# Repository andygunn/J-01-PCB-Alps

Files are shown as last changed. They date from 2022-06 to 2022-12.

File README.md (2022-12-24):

# J-01 Alps PCB

This is an Alps compatible PCB for the [J-01 keyboard](https://geekhack.org/index.php?topic=107597). Many thanks to Flex, the designer of the original PCB for their help with dimensions and layout compatibility. Additional thanks to Anjheos for the help with adding J-01 rev2 compatibility.

While it lacks support for MX switches, it has Alps switch support and the following additional features:
- Full bottom row support per the options in Via (see the following [Keyboard Layout](http://www.keyboard-layout-editor.com/#/gists/1aa1c3e0d55bc183d22bc74a1a26bc83) for more information).
- Normal, stepped, and 3800-style Capslock footprints.
- ISO Enter support - including for 1.25U vertical and horizontal rotation (Matias, DCS?), and 1.5U vertical orientation (Dell AT102).
- Some hand-solderable SMT component support, though the ATmega32U4-MU MCU is not hand-solderable.
- This PCB maintains PCB-mount MX stabilizer support, as most modern Alps keysets relased now have MX-style stabilizers. Using a plate with MX-style stabilizer cutouts will be requried to use those.

Some notable changes from the original J-01 rev1 PCB:
- Dual ground planes, instead of the GND / 5V plane on the original. It appears that the 5V ground plane on the original facilitated easier routing of the LED 5V signal, as well as power to the MCU. Since this Alps version of the PCB does not utilize in-switch LED footprints, this was changed.
- The spacing of the 6U spacebar stabilizer is different. I am not sure if the original PCB has these incorrect, or if I am using a different 6U spacebar stabilizer footprint, but that is a discrepancy.

## I provide this PCB without liability and without any guarantees regarding functionality, as expressed in the licenses under which this PCB is licensed.

Front render:
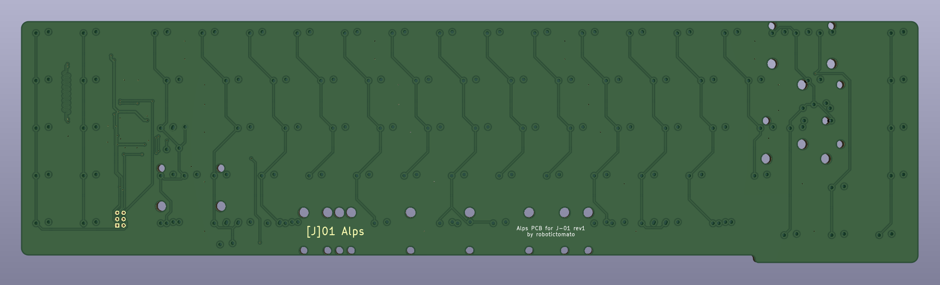
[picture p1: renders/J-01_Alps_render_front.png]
Render of front of J-01 Alps PCB


Back render:
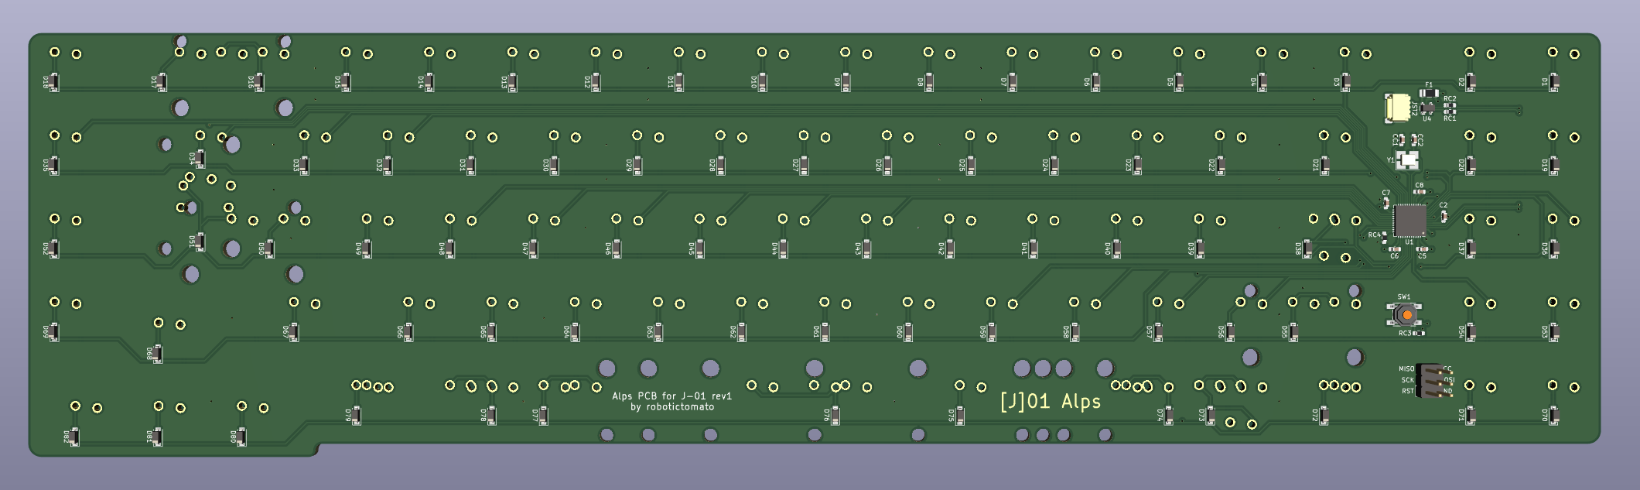
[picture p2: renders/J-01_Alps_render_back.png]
Render of back of J-01 Alps PCB


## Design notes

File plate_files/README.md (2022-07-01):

# J-01 Alps Plate Files

These are some Alps-compatible plate files for the [J-01 keyboard](https://geekhack.org/index.php?topic=107597). These are derived from the original plate files found on the [Prototypist website](https://prototypist.net/pages/resources).

There are three files provided. These are:
* A .dxf of an Alps-stabilizer file. This utilizes an AT101 bottom row, but older Alps sets were all a bit different, so you may encounter issues with the placement of the stabilizer clips and the vertical pole guide. There are cutouts for a flipped spacebar orientation, but this is untested. You may need to adjust for your specific keyset.
* A .dxf of an MX-stabilizer file. This is close to the production plate for the J-01 rev1, but with Alps switch cutouts. This is intended for DCS-style keycaps, with MX-stabilizer compatibility on all stabilized keys. Other keysets may not work, you may need to adjust for your specific keyset. NOTE: This plate has not been fully tested, you may run into issues.
* A set of Gerber files based on the MX-stabilizer file. The same notes and disclaimers apply here. NOTE: This plate has not been prototyped or tested in any way, you may run into issues.

It is recommended to cut these files in material 1.2mm thick - any thicker may prevent the Alps switches from clipping in properly.

## I provide these plate files without liability and without any guarantees regarding functionality, as expressed in the licenses under which these plate files are licensed.

Alps-stabilizer plate file outline:
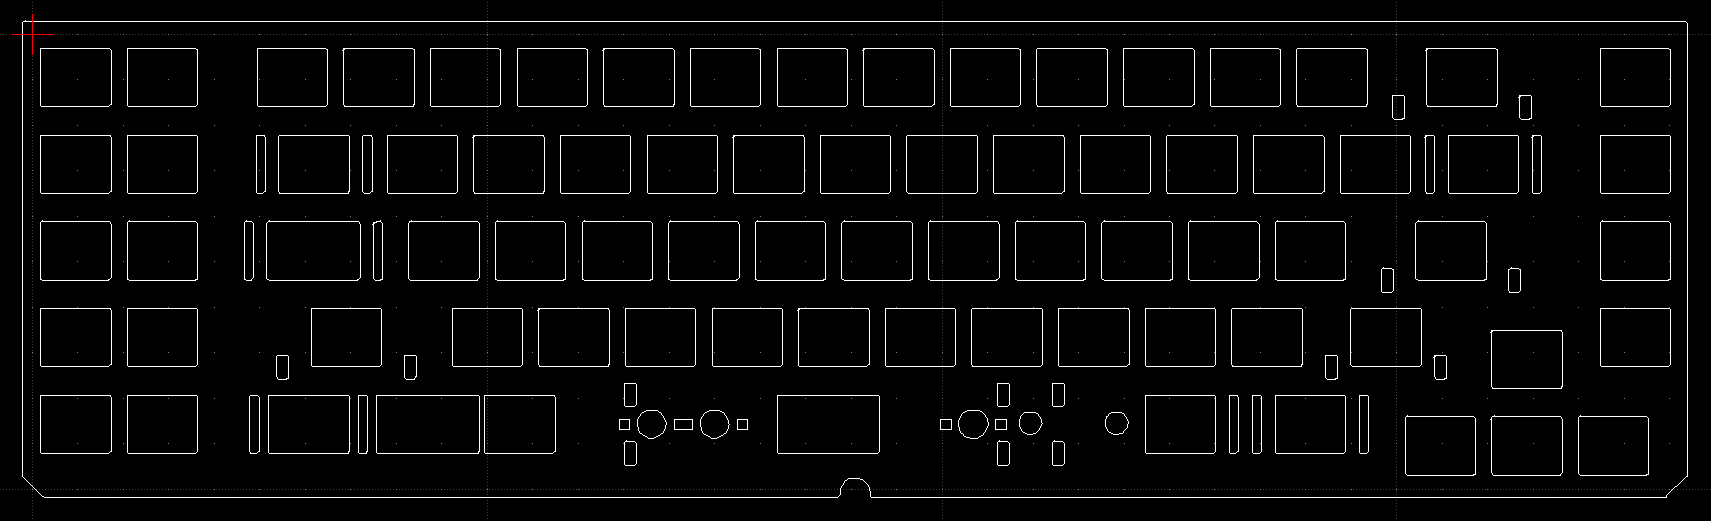
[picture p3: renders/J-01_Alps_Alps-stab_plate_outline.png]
Screenshot of Alps-stabilizer plate file


MX stabilizer plate file outline:
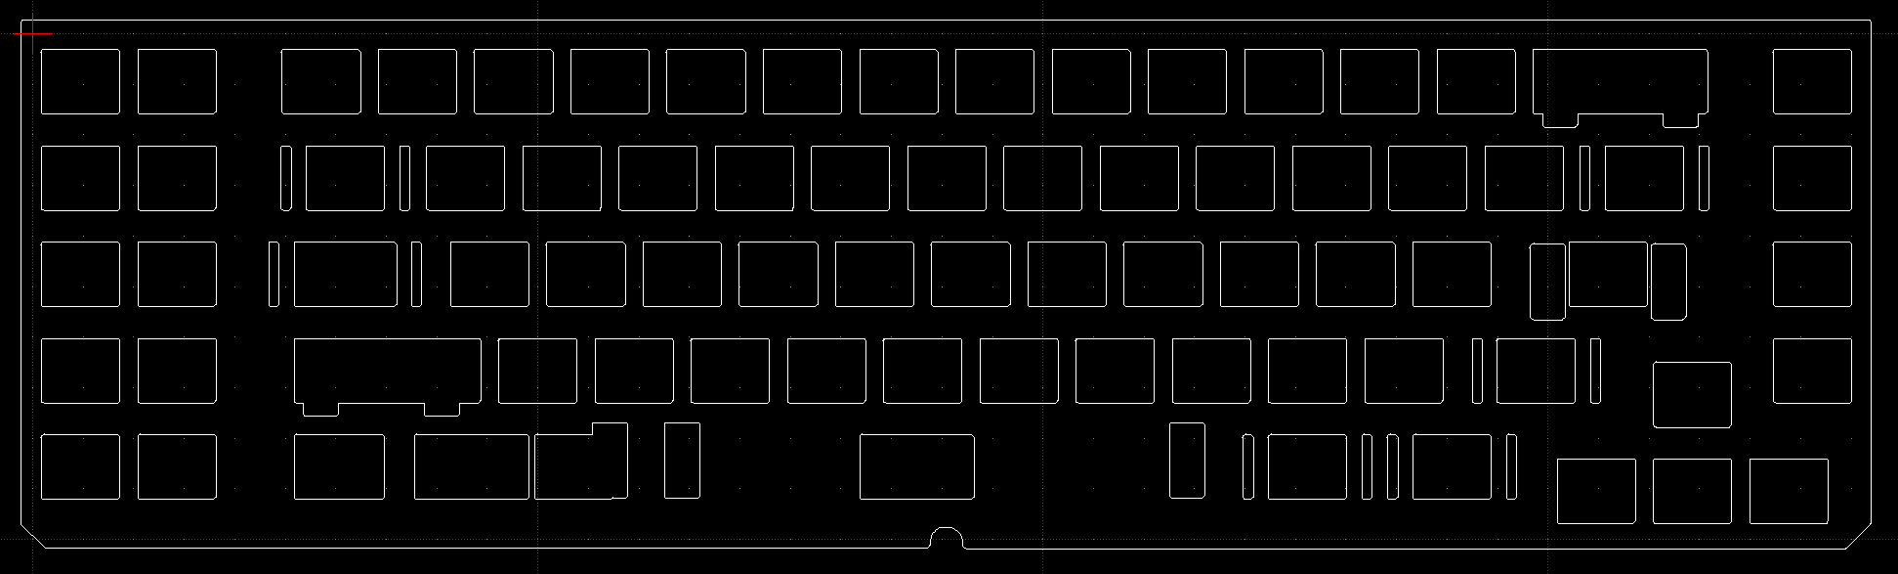
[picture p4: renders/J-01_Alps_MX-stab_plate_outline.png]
Screenshot of MX-stabilizer plate file


FR4 plate file render:
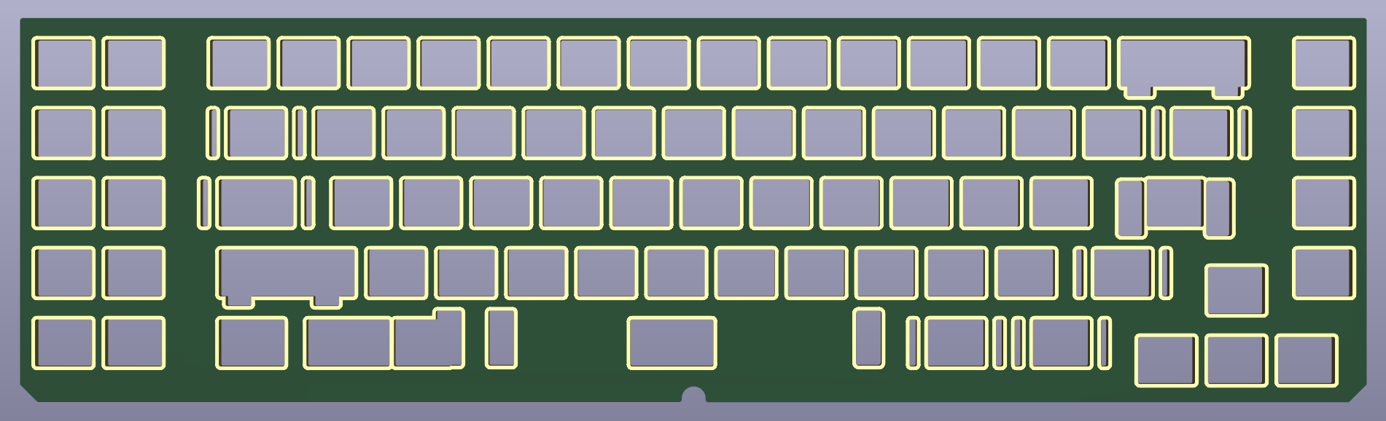
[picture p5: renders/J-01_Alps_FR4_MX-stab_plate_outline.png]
Render of J-01 Alps FR4 plate file


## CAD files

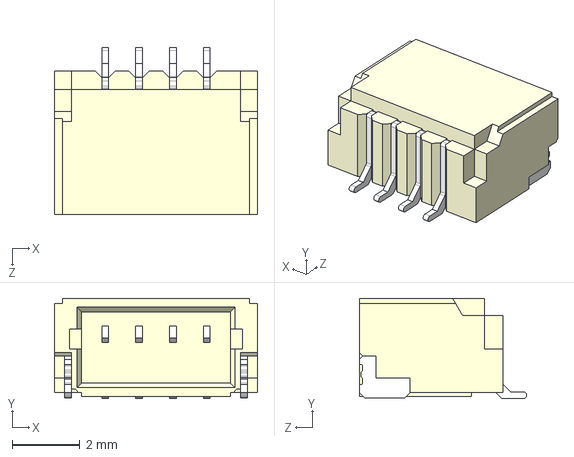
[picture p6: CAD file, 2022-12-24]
JST-3d-model/SM04B-SRSS-TB(LF)(SN)--3DModel-STEP-56544.STEP
6.00 x 2.96 x 4.95 mm

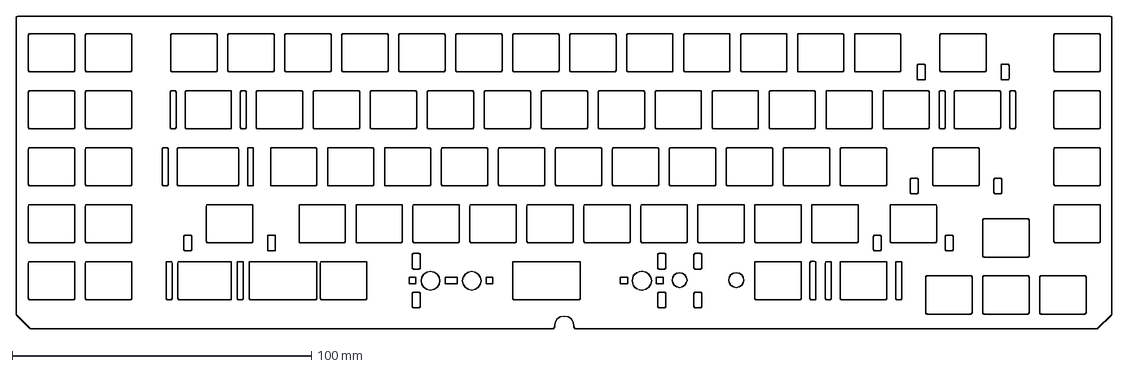
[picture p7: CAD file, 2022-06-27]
plate_files/J-01Rev-1_Alps_-_Alps-stabs.dxf
366.3 x 104.6 mm

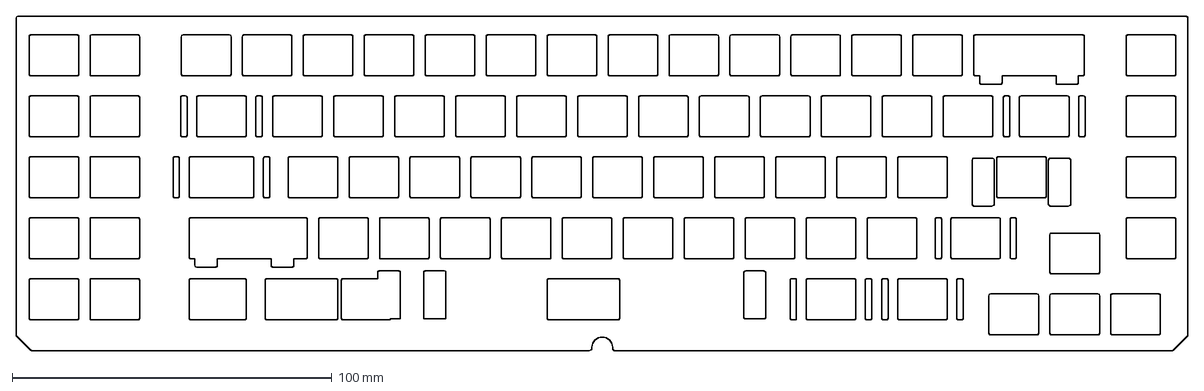
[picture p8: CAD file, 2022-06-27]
plate_files/J-01Rev-1_Alps_-_MX stabs.dxf
366.3 x 104.6 mm

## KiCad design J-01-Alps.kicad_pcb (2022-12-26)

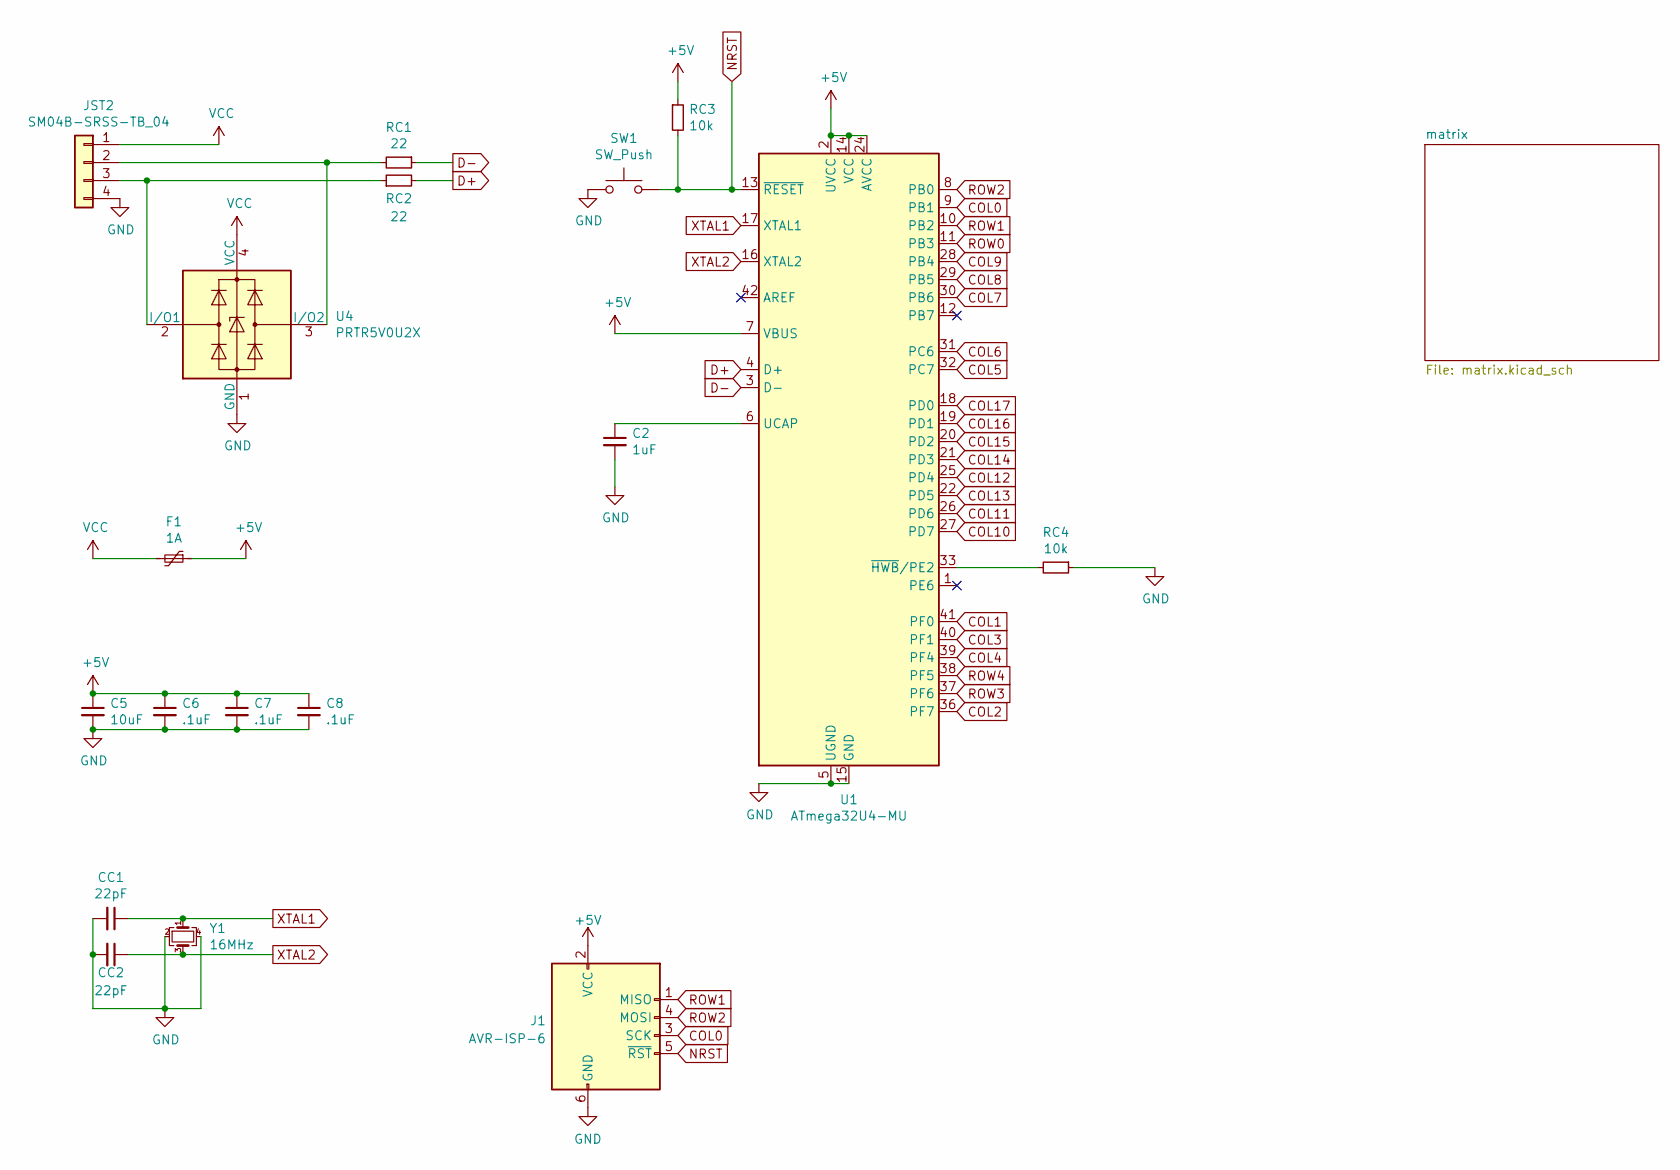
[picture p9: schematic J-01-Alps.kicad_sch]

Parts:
C2: 1uF; C_0603_1608Metric_Pad1.08x0.95mm_HandSolder; LCSC C15849
C5: 10uF; C_0603_1608Metric_Pad1.08x0.95mm_HandSolder; LCSC C19702
C6, C7, C8: .1uF; C_0603_1608Metric_Pad1.08x0.95mm_HandSolder; LCSC C14663
CC1, CC2: 22pF; C_0603_1608Metric_Pad1.08x0.95mm_HandSolder; LCSC C1653
F1: 1A; Fuse_1206_3216Metric_Pad1.42x1.75mm_HandSolder; LCSC C315893
J1: AVR-ISP-6; PinHeader_2x03_P2.54mm_Vertical
JST2: SM04B-SRSS-TB_04; JST_SH_SM04B-SRSS-TB_1x04-1MP_P1.00mm_Horizontal; LCSC C160404
RC1, RC2: 22; R_0603_1608Metric_Pad0.98x0.95mm_HandSolder; LCSC C23345
RC3, RC4: 10k; R_0603_1608Metric_Pad0.98x0.95mm_HandSolder; LCSC C25804
SW1: SW_Push; SKQGADE010
U1: ATmega32U4-MU; QFN-44-1EP_7x7mm_P0.5mm_EP5.15x5.15mm
U4: PRTR5V0U2X; SOT143B; LCSC C12333
Y1: 16MHz; Crystal_SMD_3225-4Pin_3.2x2.5mm_HandSoldering; LCSC C255906

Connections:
+5V: C5.1, C6.1, C7.1, C8.1, F1.1, J1.2 (VCC), RC3.1, U1.2 (UVCC), U1.7 (VBUS), U1.14 (VCC), U1.24 (AVCC), U1.34 (VCC), U1.44 (AVCC)
COL0: J1.3 (SCK), U1.9 (PB1); also elsewhere on the board
COL1: U1.41 (PF0); also elsewhere on the board
COL2: U1.36 (PF7); also elsewhere on the board
COL3: U1.40 (PF1); also elsewhere on the board
COL4: U1.39 (PF4); also elsewhere on the board
COL5: U1.32 (PC7); also elsewhere on the board
COL6: U1.31 (PC6); also elsewhere on the board
COL7: U1.30 (PB6); also elsewhere on the board
COL8: U1.29 (PB5); also elsewhere on the board
COL9: U1.28 (PB4); also elsewhere on the board
COL10: U1.27 (PD7); also elsewhere on the board
COL11: U1.26 (PD6); also elsewhere on the board
COL12: U1.25 (PD4); also elsewhere on the board
COL13: U1.22 (PD5); also elsewhere on the board
COL14: U1.21 (PD3); also elsewhere on the board
COL15: U1.20 (PD2); also elsewhere on the board
COL16: U1.19 (PD1); also elsewhere on the board
COL17: U1.18 (PD0); also elsewhere on the board
D+: RC2.2, U1.4 (D+)
D-: RC1.1, U1.3 (D-)
GND: C2.2, C5.2, C6.2, C7.2, C8.2, CC1.2, CC2.2, J1.6 (GND), JST2.4, RC4.1, SW1.1, U1.5 (UGND), U1.15 (GND), U1.23 (GND), U1.35 (GND), U1.43 (GND), U4.1 (GND), Y1.2, Y1.4
NRST: J1.5 (~RST), RC3.2, SW1.2, U1.13 (~RESET)
unnamed: C2.1, U1.6 (UCAP)
unnamed: JST2.2, RC1.2, U4.3 (I/O2)
unnamed: JST2.3, RC2.1, U4.2 (I/O1)
unnamed: RC4.2, U1.33 (~HWB/PE2)
ROW0: U1.11 (PB3); also elsewhere on the board
ROW1: J1.1 (MISO), U1.10 (PB2); also elsewhere on the board
ROW2: J1.4 (MOSI), U1.8 (PB0); also elsewhere on the board
ROW3: U1.37 (PF6); also elsewhere on the board
ROW4: U1.38 (PF5); also elsewhere on the board
VCC: F1.2, JST2.1, U4.4 (VCC)
XTAL1: CC1.1, U1.17 (XTAL1), Y1.1
XTAL2: CC2.1, U1.16 (XTAL2), Y1.3

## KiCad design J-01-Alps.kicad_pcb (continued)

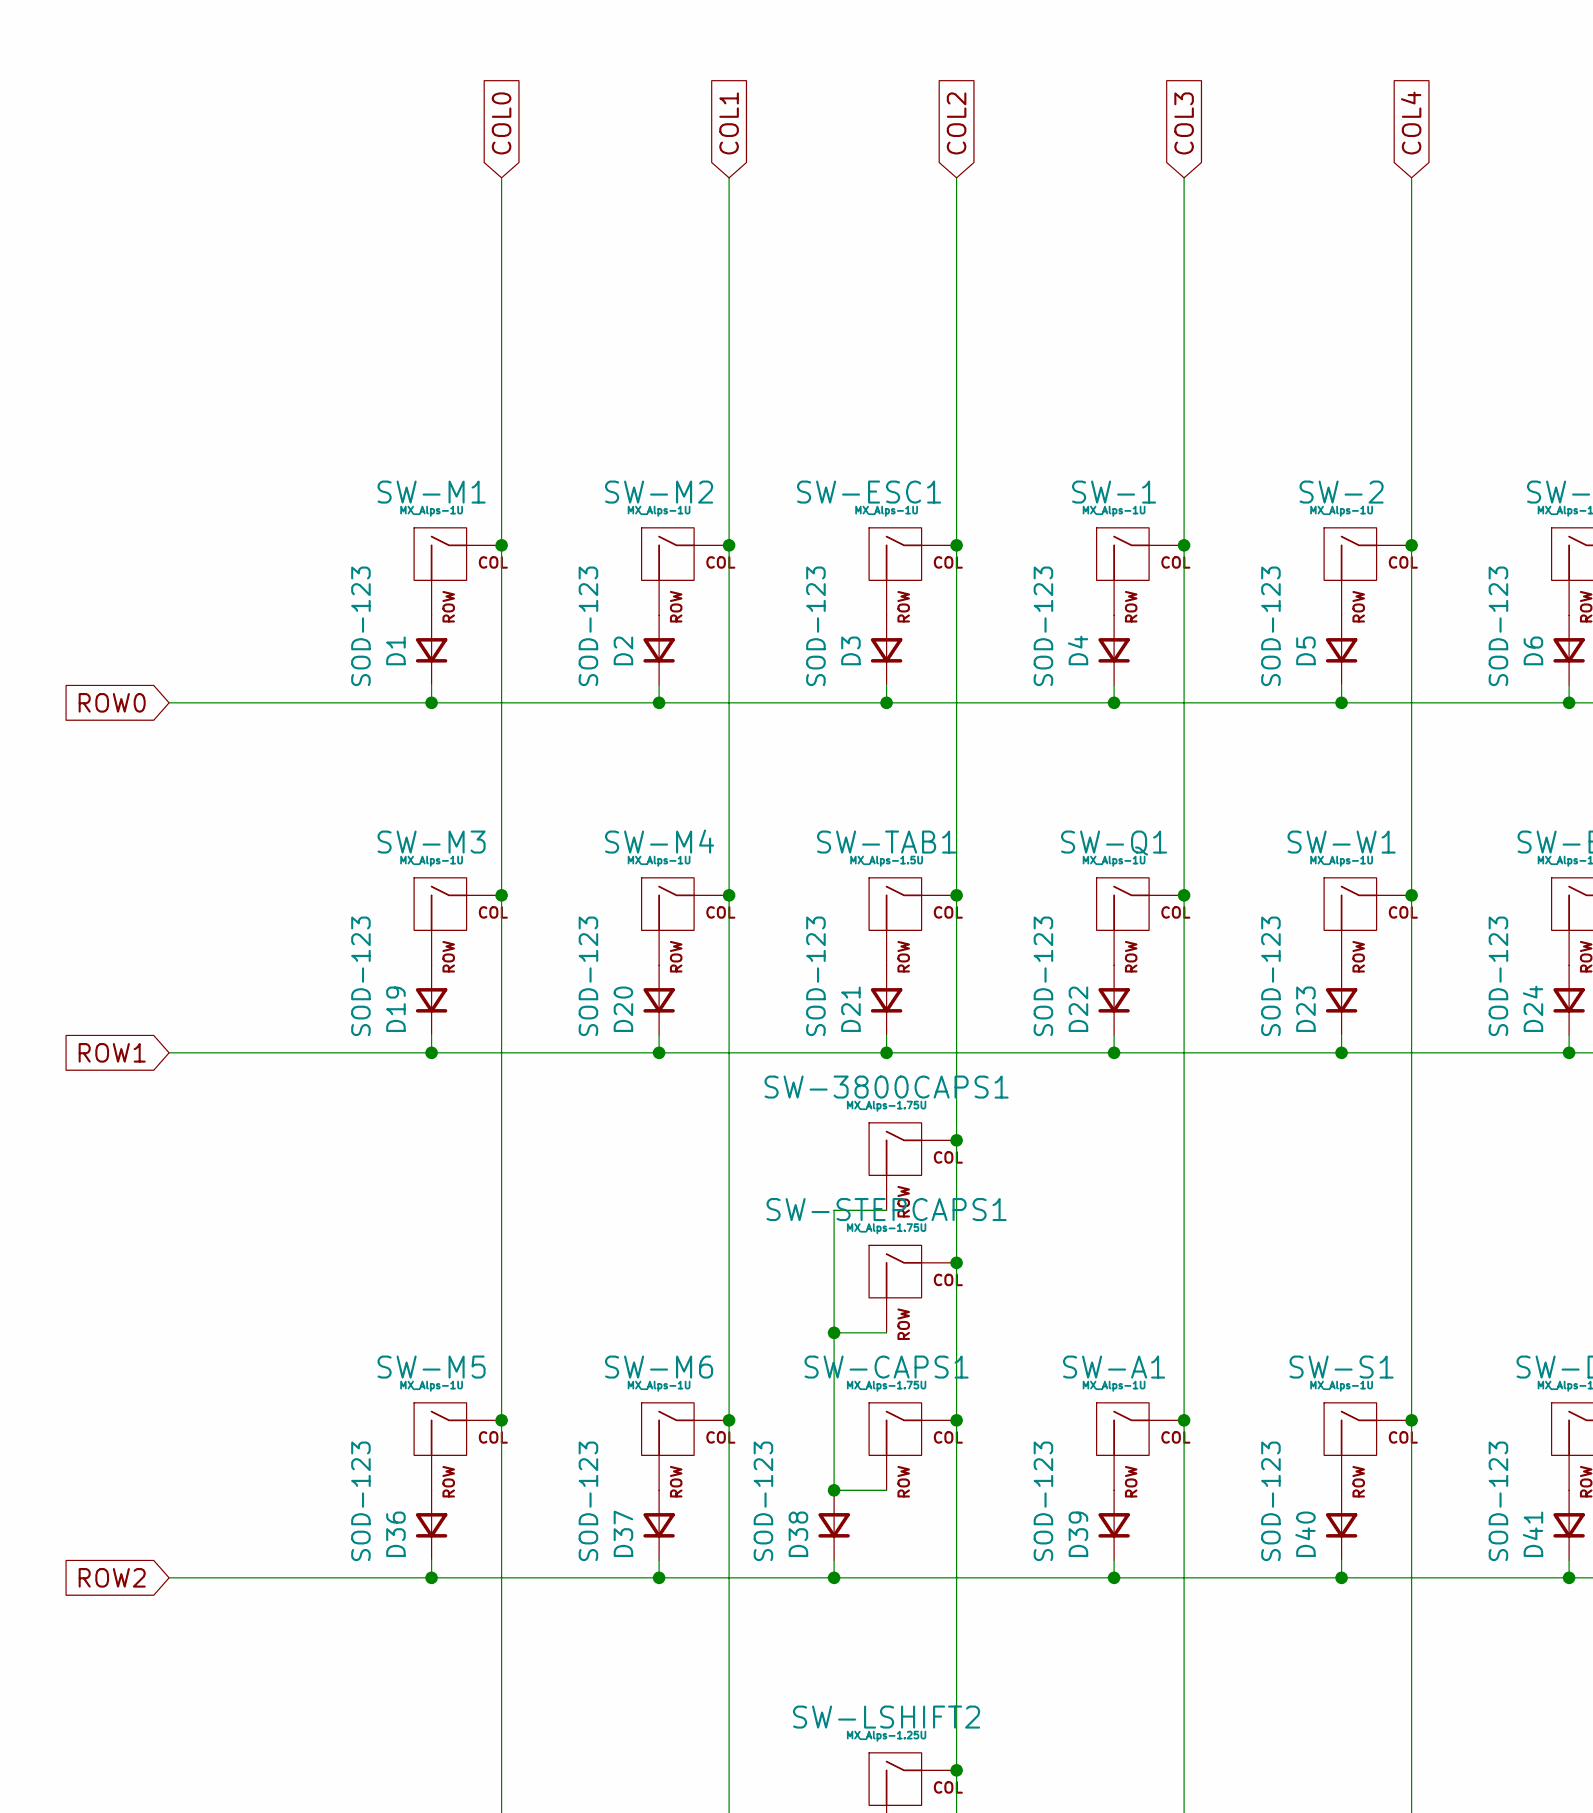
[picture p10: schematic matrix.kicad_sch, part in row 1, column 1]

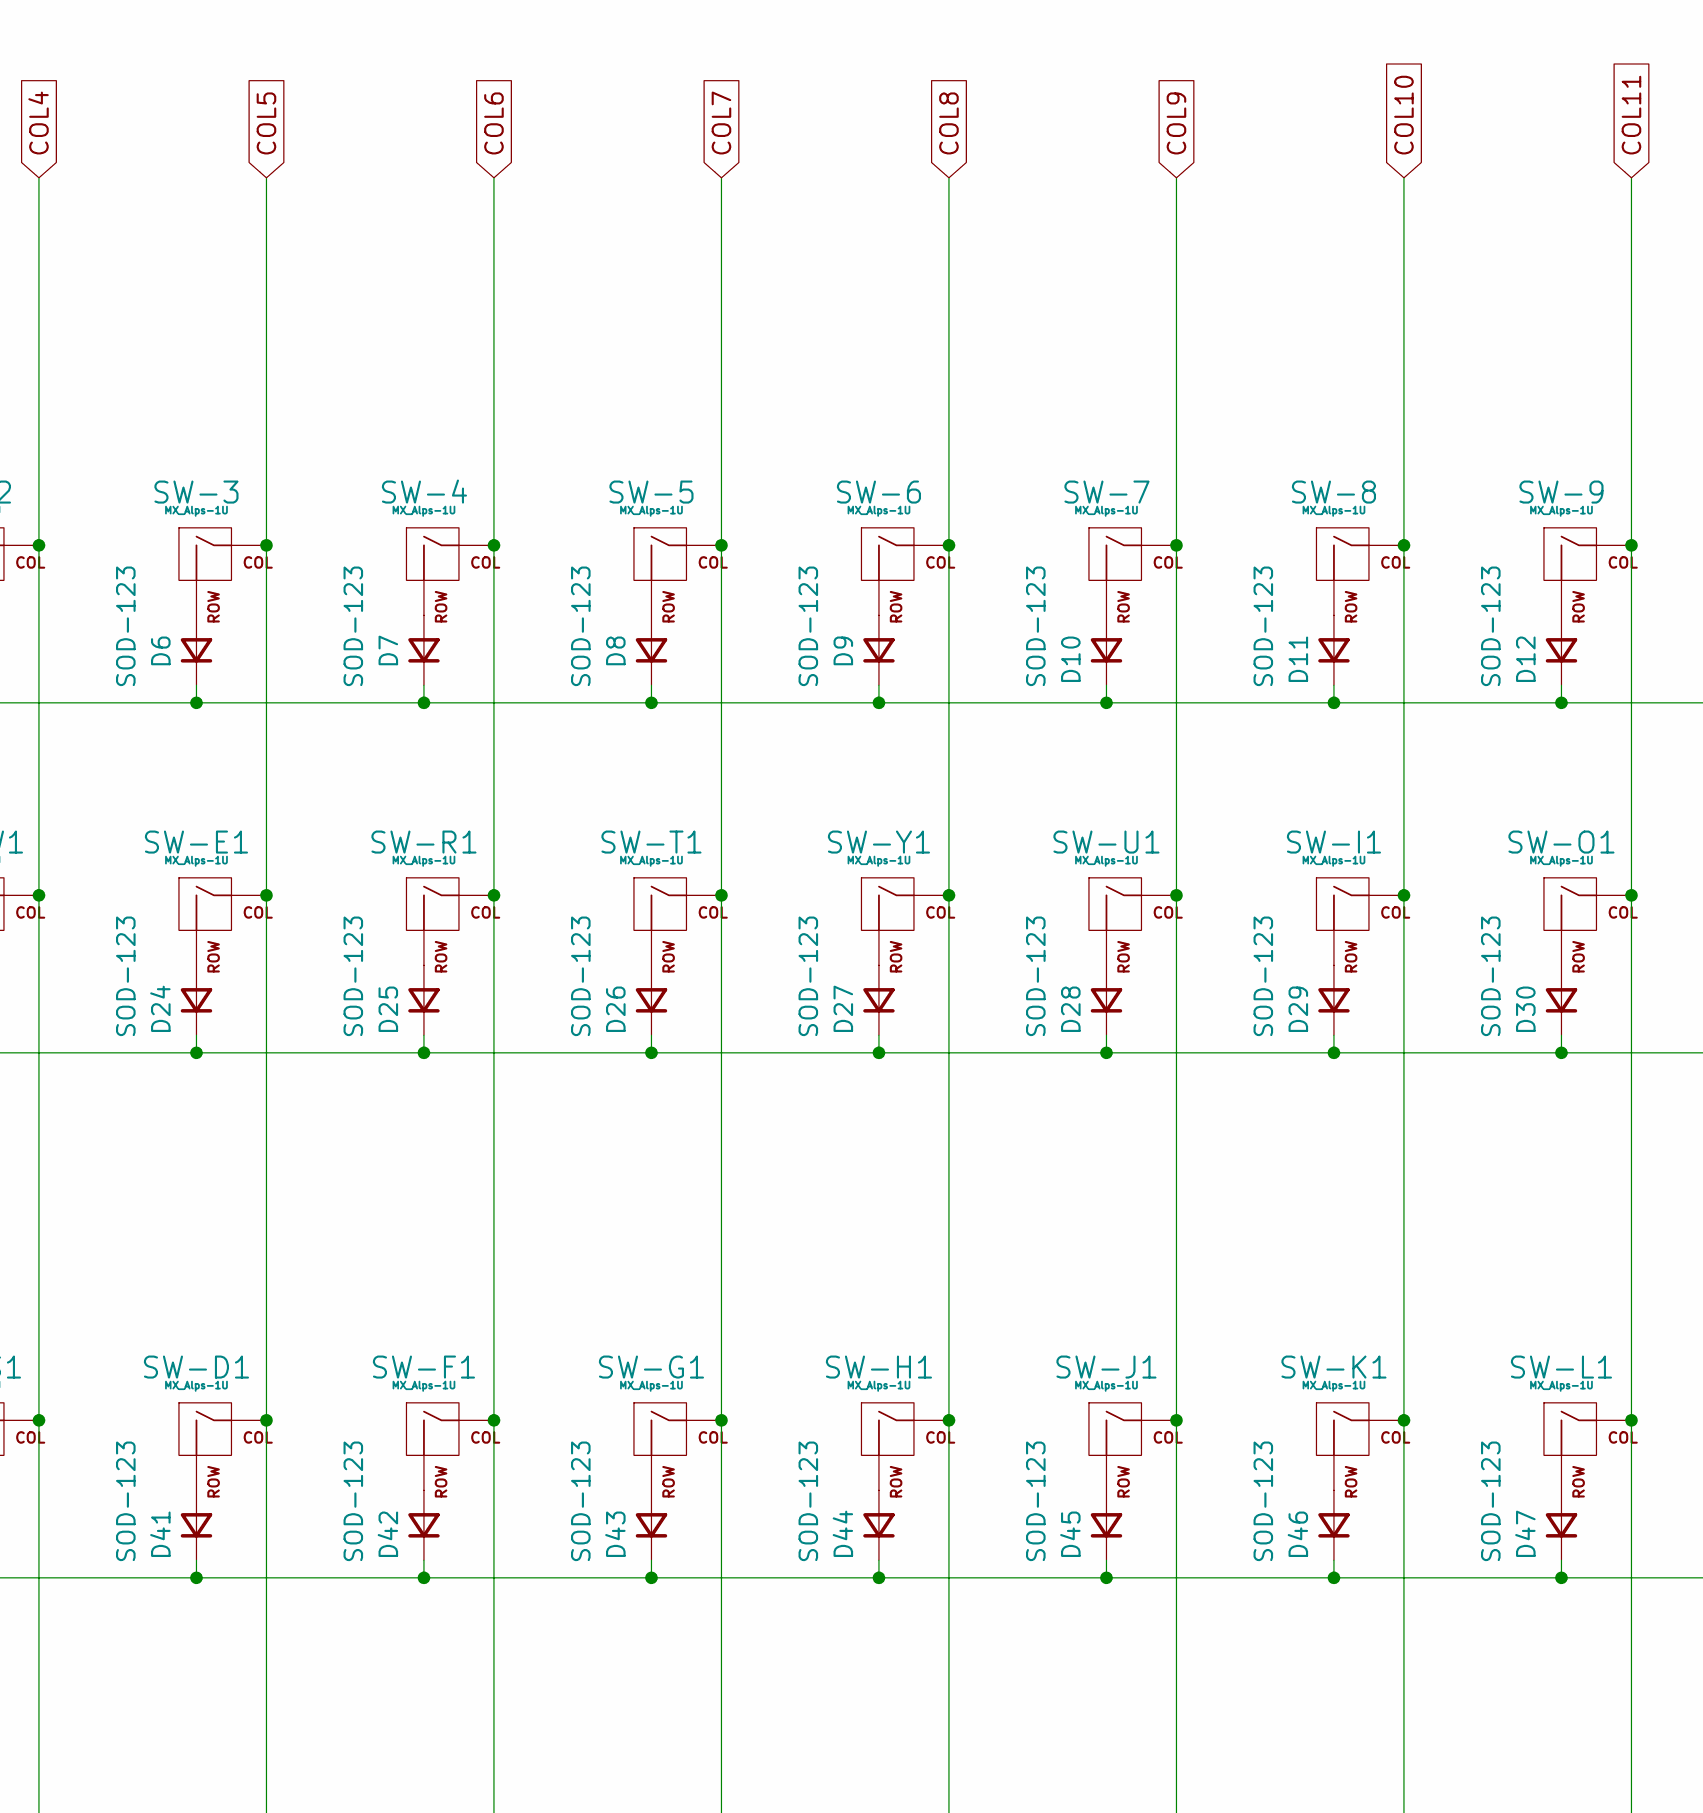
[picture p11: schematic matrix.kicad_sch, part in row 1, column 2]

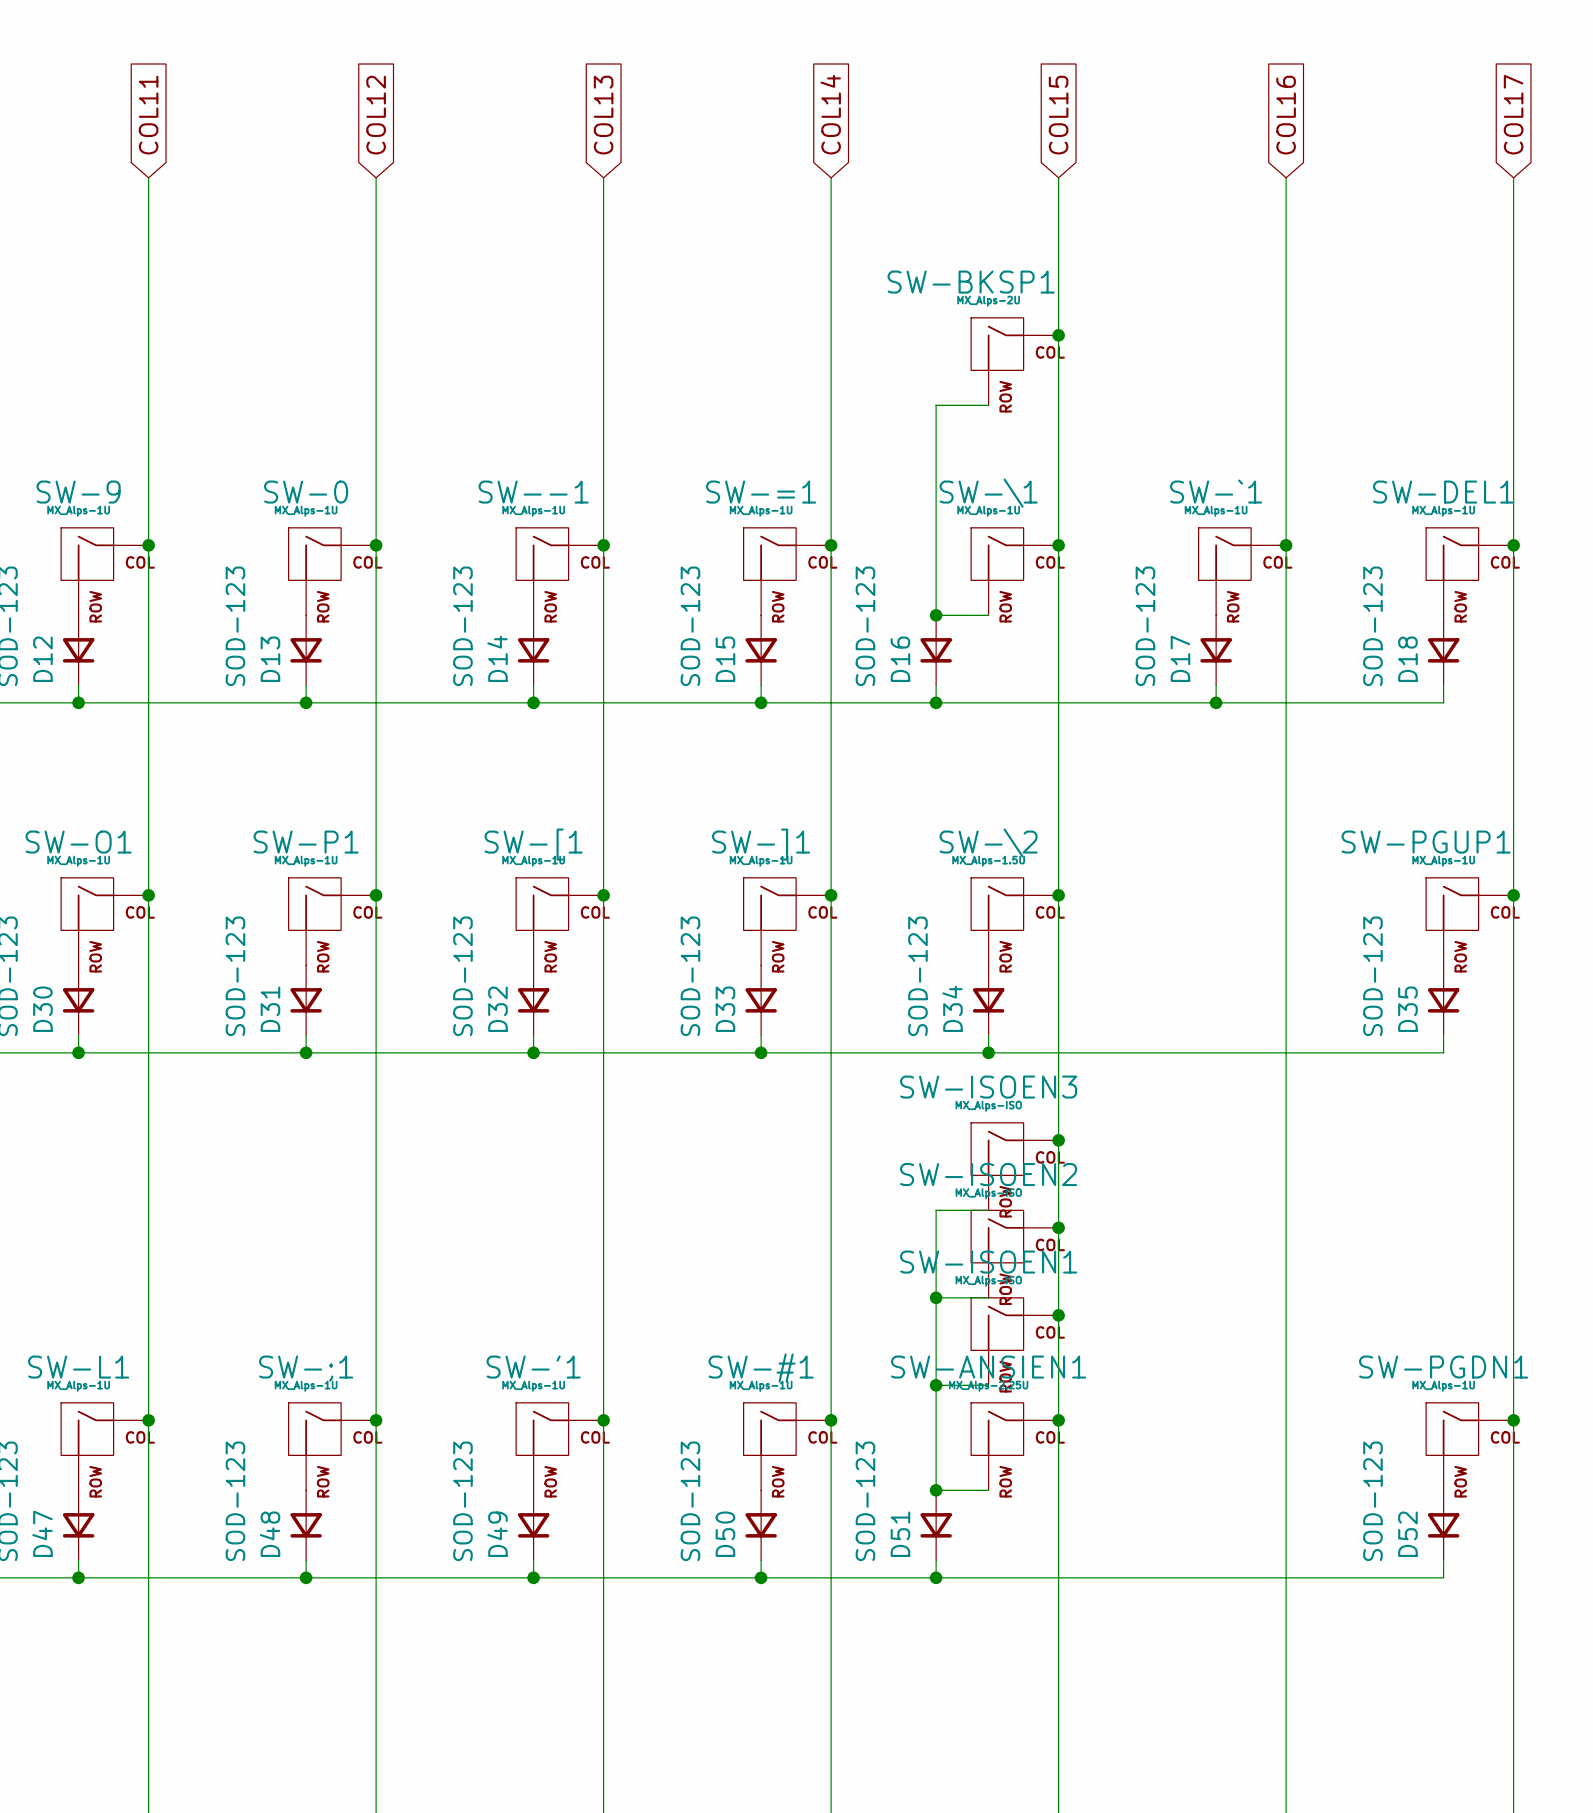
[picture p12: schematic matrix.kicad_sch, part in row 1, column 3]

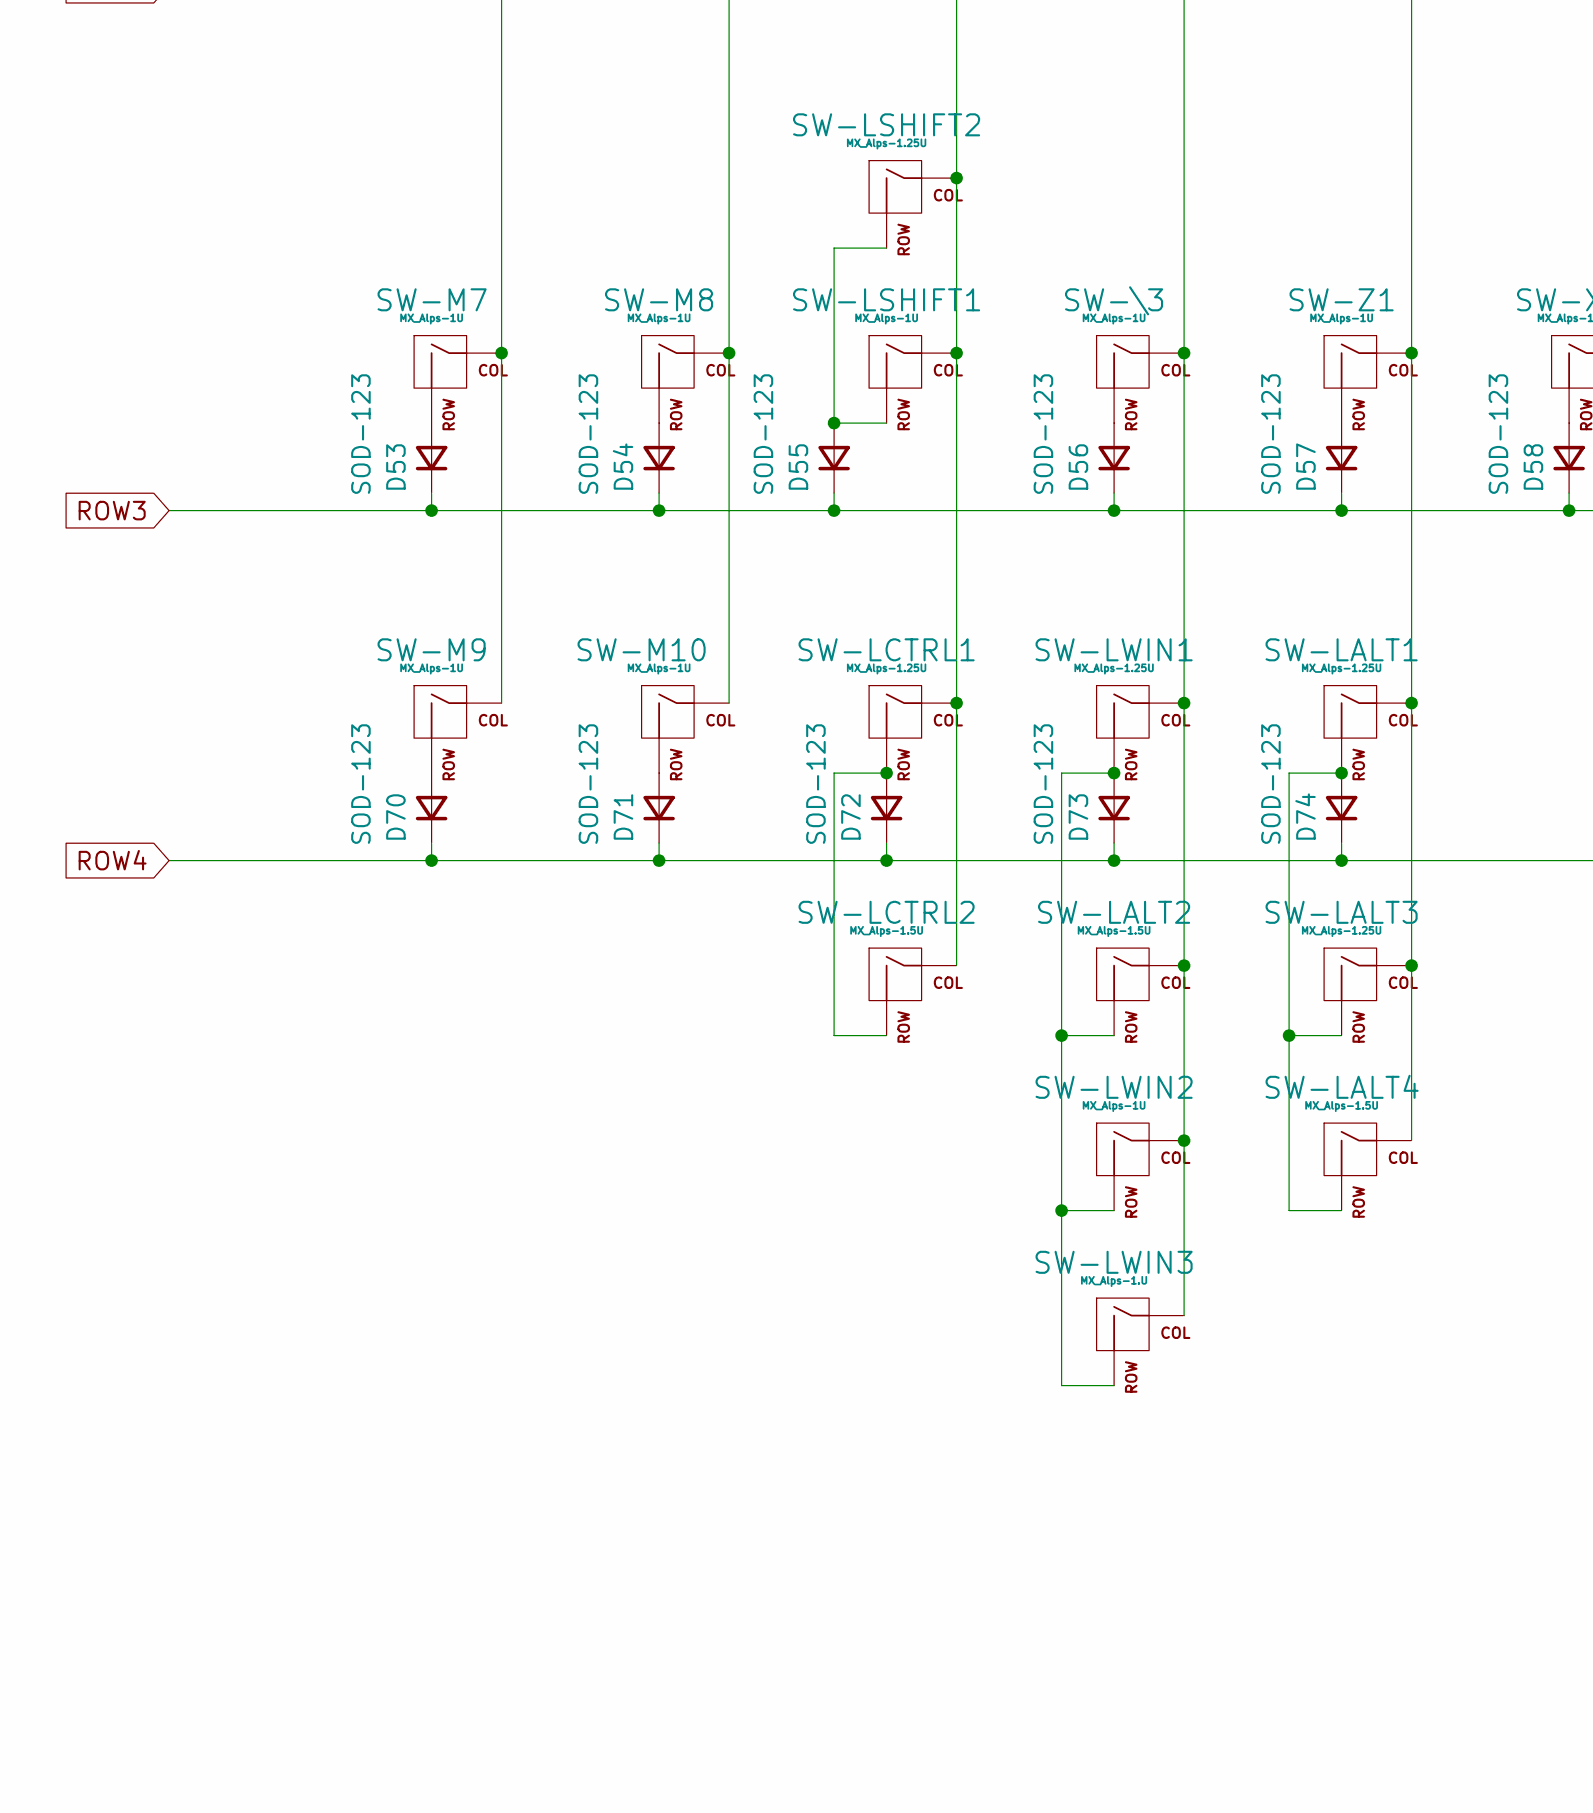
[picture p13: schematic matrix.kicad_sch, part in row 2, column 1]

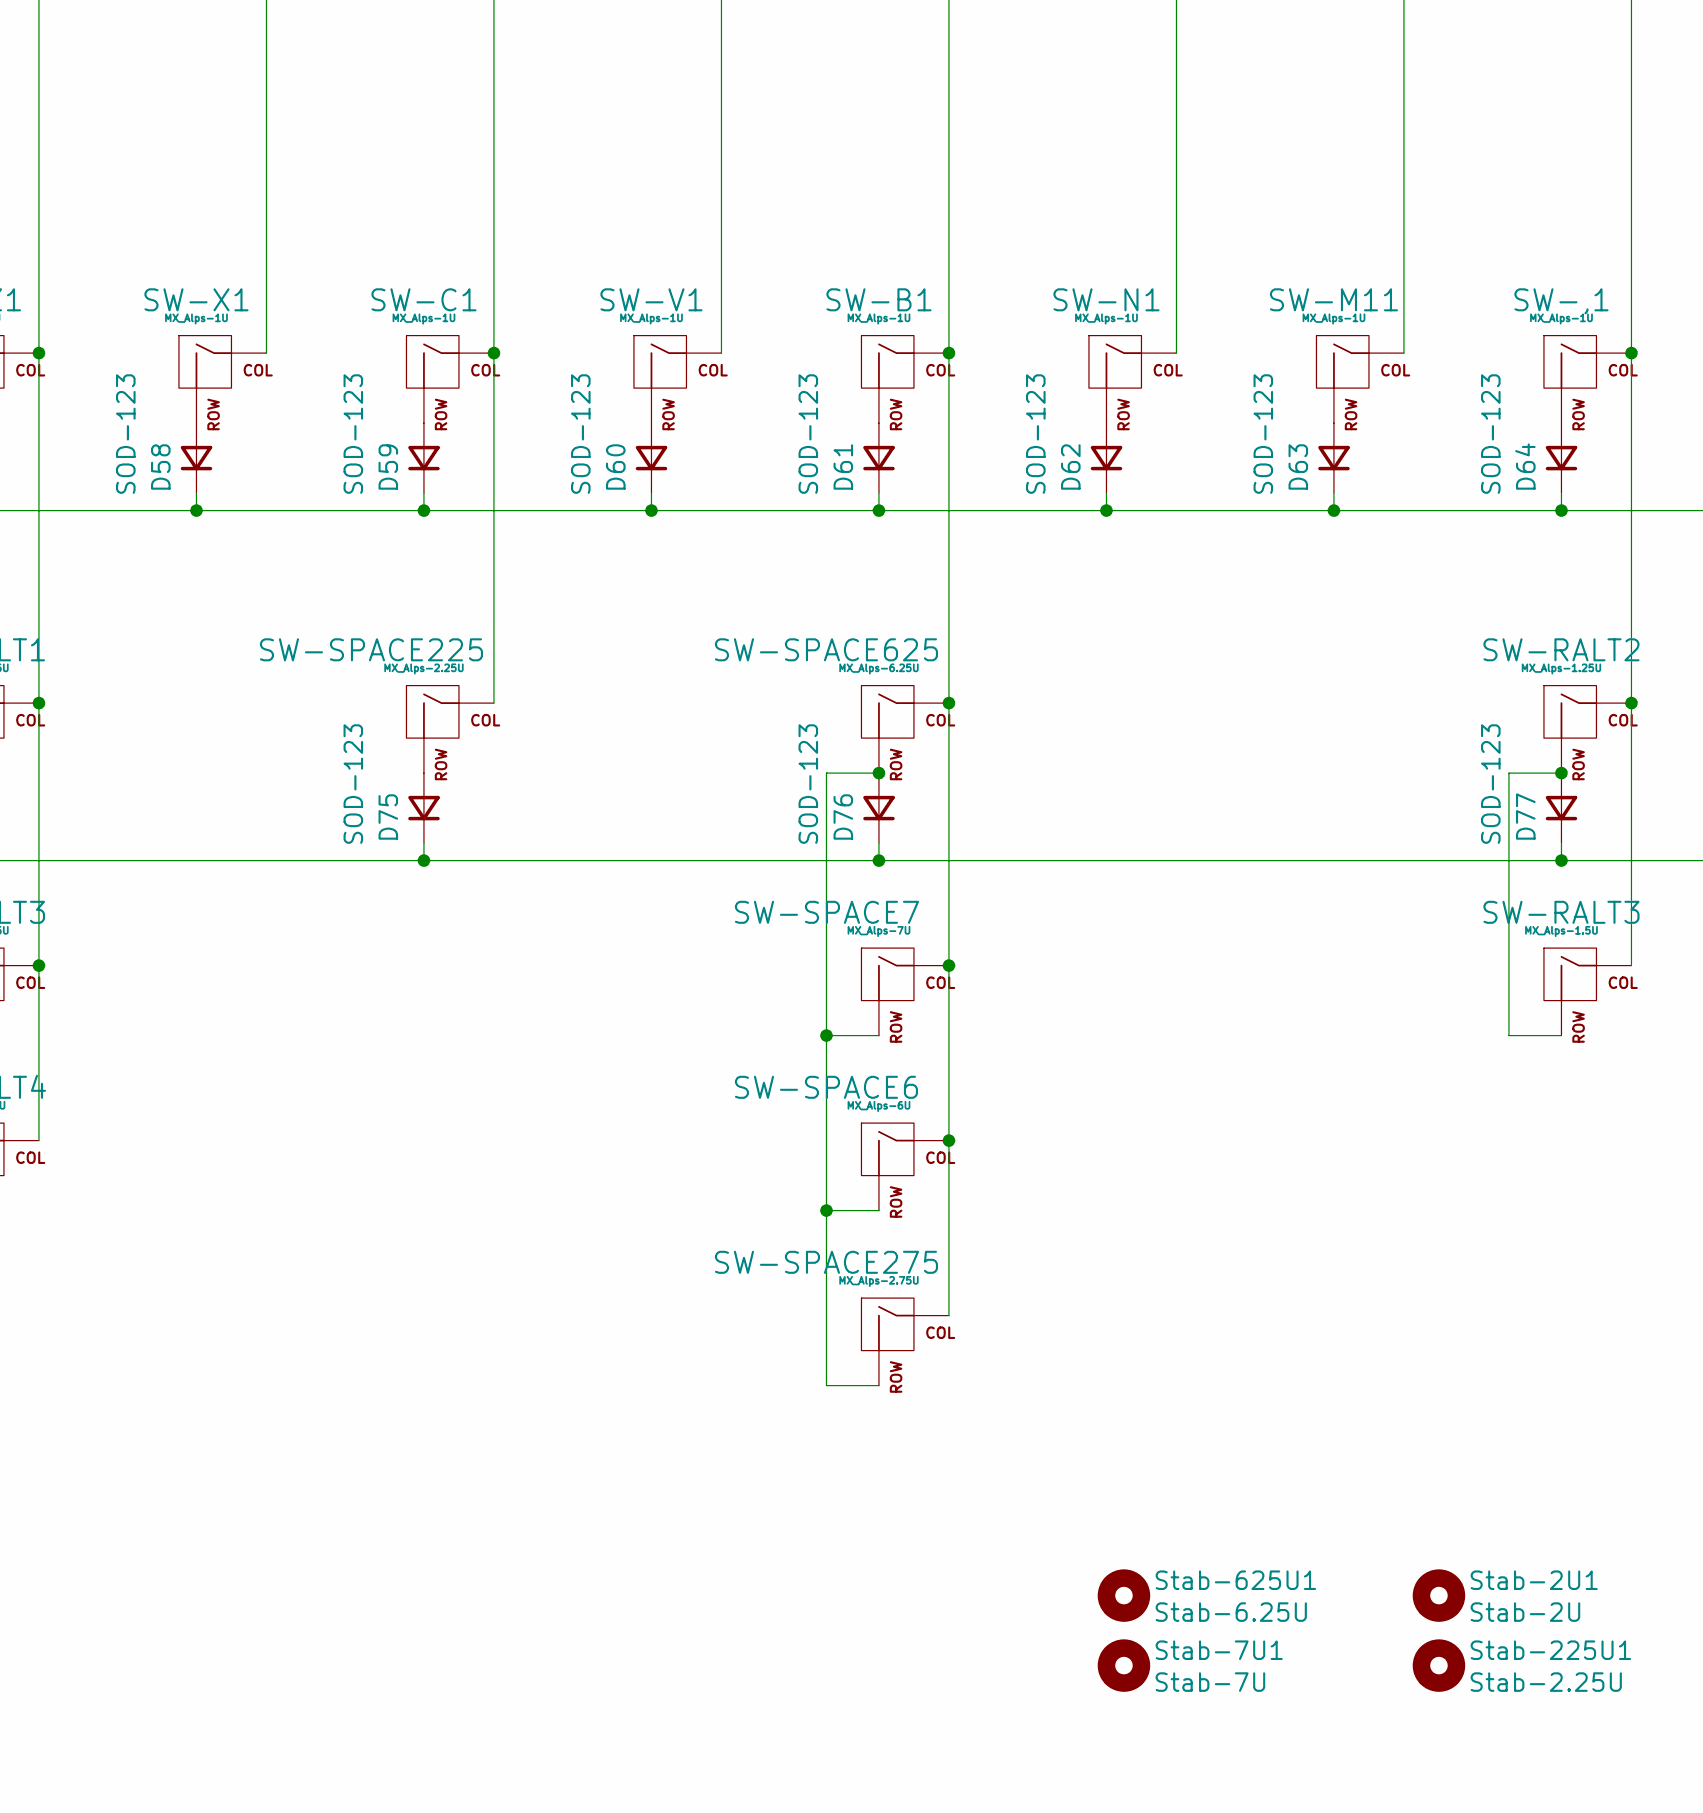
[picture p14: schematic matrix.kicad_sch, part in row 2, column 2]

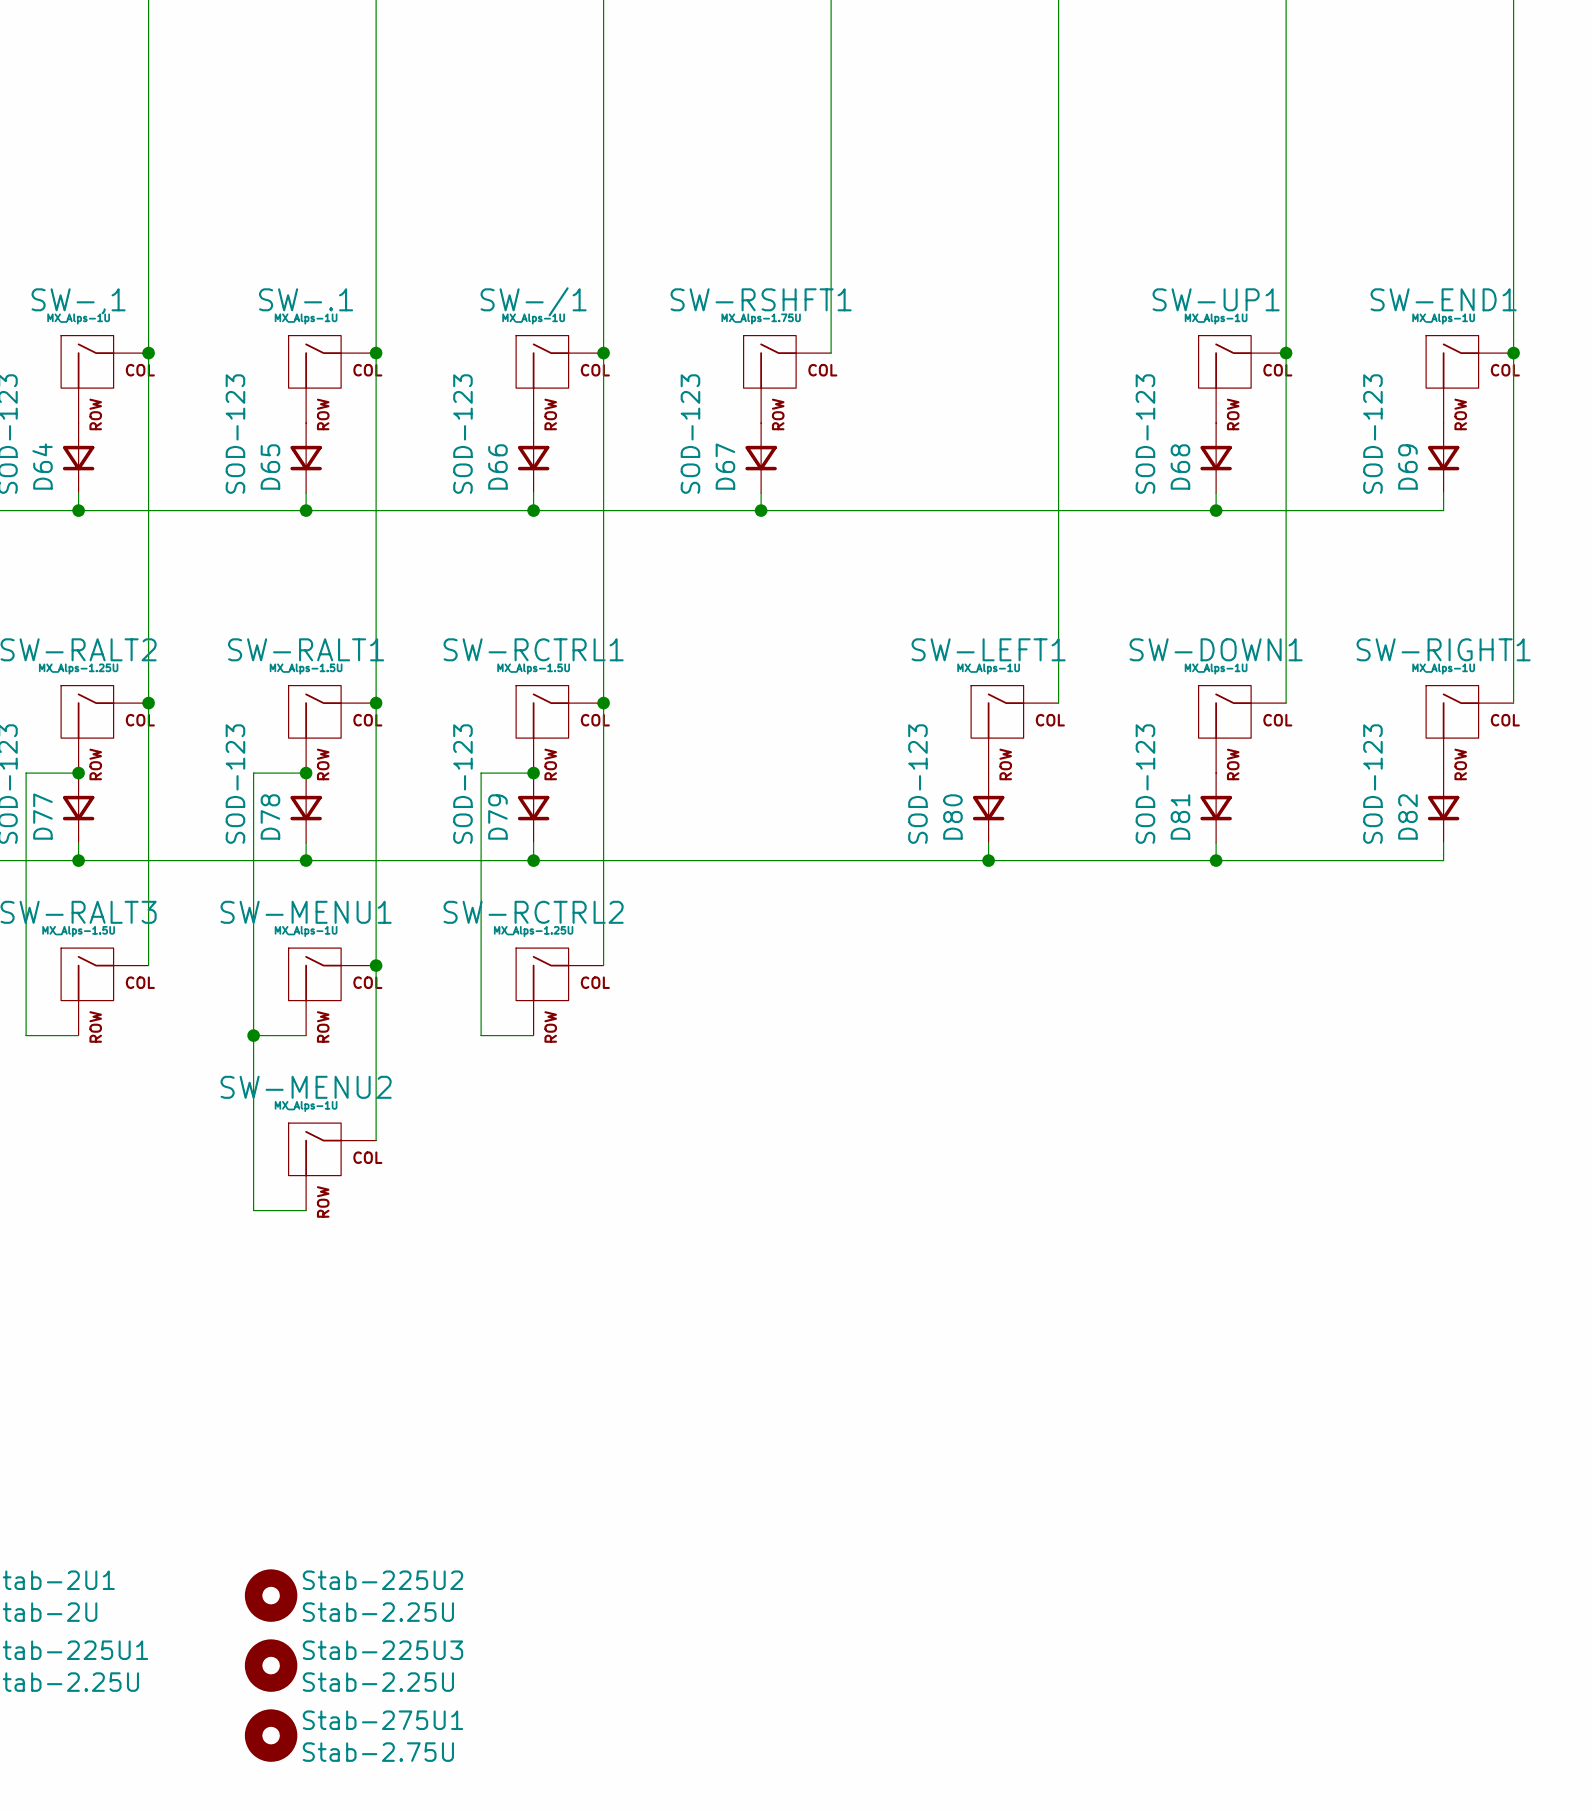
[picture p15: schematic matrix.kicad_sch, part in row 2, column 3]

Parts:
D1, D2, D3, D4, D5, D6, D7, D8, D9, D10, D11, D12, D13, D14, D15, D16, D17, D18, D19, D20, D21, D22, D23, D24, D25, D26, D27, D28, D29, D30, D31, D32, D33, D34, D35, D36, D37, D38, D39, D40, D41, D42, D43, D44, D45, D46, D47, D48, D49, D50, D51, D52, D53, D54, D55, D56, D57, D58, D59, D60, D61, D62, D63, D64, D65, D66, D67, D68, D69, D70, D71, D72, D73, D74, D75, D76, D77, D78, D79, D80, D81, D82: SOD-123; D_SOD-123; LCSC C81598
SW-0, SW-1, SW-2, SW-3, SW-4, SW-5, SW-6, SW-7, SW-8, SW-9, SW-.1: MX_Alps-1U; ALPS-1U
SW-3800CAPS1: MX_Alps-1.75U; ALPS-1.5U
SW-#1: MX_Alps-1U; ALPS-1U
SW-'1: MX_Alps-1U; ALPS-1U
SW-,1: MX_Alps-1U; ALPS-1U
SW--1: MX_Alps-1U; ALPS-1U
SW-/1: MX_Alps-1U; ALPS-1U
SW-;1: MX_Alps-1U; ALPS-1U
SW-=1: MX_Alps-1U; ALPS-1U
SW-A1: MX_Alps-1U; ALPS-1U
SW-ANSIEN1: MX_Alps-2.25U; ALPS-2.25U
SW-B1: MX_Alps-1U; ALPS-1U
SW-BKSP1: MX_Alps-2U; ALPS-2U
SW-C1: MX_Alps-1U; ALPS-1U
SW-CAPS1: MX_Alps-1.75U; ALPS-1.75U
SW-D1: MX_Alps-1U; ALPS-1U
SW-DEL1: MX_Alps-1U; ALPS-1U
SW-DOWN1: MX_Alps-1U; ALPS-1U
SW-E1: MX_Alps-1U; ALPS-1U
SW-END1: MX_Alps-1U; ALPS-1U
SW-ESC1: MX_Alps-1U; ALPS-1U
SW-F1: MX_Alps-1U; ALPS-1U
SW-G1: MX_Alps-1U; ALPS-1U
SW-H1: MX_Alps-1U; ALPS-1U
SW-I1: MX_Alps-1U; ALPS-1U
SW-ISOEN1: MX_Alps-ISO; ALPS-ISO-FLIPPED
SW-ISOEN2, SW-ISOEN3: MX_Alps-ISO; ALPS-1U
SW-J1: MX_Alps-1U; ALPS-1U
SW-K1: MX_Alps-1U; ALPS-1U
SW-L1: MX_Alps-1U; ALPS-1U
SW-LALT1, SW-LALT3: MX_Alps-1.25U; ALPS-1.25U
SW-LALT2, SW-LALT4: MX_Alps-1.5U; ALPS-1.5U
SW-LCTRL1: MX_Alps-1.25U; ALPS-1.25U
SW-LCTRL2: MX_Alps-1.5U; ALPS-1.5U
SW-LEFT1: MX_Alps-1U; ALPS-1U
SW-LSHIFT1: MX_Alps-1U; ALPS-2.25U
SW-LSHIFT2: MX_Alps-1.25U; ALPS-1.25U
SW-LWIN1: MX_Alps-1.25U; ALPS-1.25U
SW-LWIN2: MX_Alps-1U; ALPS-1U
SW-LWIN3: MX_Alps-1.U; ALPS-1U
SW-M1, SW-M2, SW-M3, SW-M4, SW-M5, SW-M6, SW-M7, SW-M8, SW-M9, SW-M10, SW-M11: MX_Alps-1U; ALPS-1U
SW-MENU1, SW-MENU2: MX_Alps-1U; ALPS-1U
SW-N1: MX_Alps-1U; ALPS-1U
SW-O1: MX_Alps-1U; ALPS-1U
SW-P1: MX_Alps-1U; ALPS-1U
SW-PGDN1: MX_Alps-1U; ALPS-1U
SW-PGUP1: MX_Alps-1U; ALPS-1U
SW-Q1: MX_Alps-1U; ALPS-1U
SW-R1: MX_Alps-1U; ALPS-1U
SW-RALT1, SW-RALT3: MX_Alps-1.5U; ALPS-1.5U
SW-RALT2: MX_Alps-1.25U; ALPS-1.25U
SW-RCTRL1: MX_Alps-1.5U; ALPS-1.5U
SW-RCTRL2: MX_Alps-1.25U; ALPS-1.25U
SW-RIGHT1: MX_Alps-1U; ALPS-1U
SW-RSHFT1: MX_Alps-1.75U; ALPS-1.75U
SW-S1: MX_Alps-1U; ALPS-1U
SW-SPACE6: MX_Alps-6U; MX-6U-Centered-ReversedStabilizers-NoLED
SW-SPACE7: MX_Alps-7U; ALPS-7U
SW-SPACE225: MX_Alps-2.25U; ALPS-2.25U
SW-SPACE275: MX_Alps-2.75U; ALPS-2.75U
SW-SPACE625: MX_Alps-6.25U; ALPS-6.25U
SW-STEPCAPS1: MX_Alps-1.75U; ALPS-1.25U
SW-T1: MX_Alps-1U; ALPS-1U
SW-TAB1: MX_Alps-1.5U; ALPS-1.5U
SW-U1: MX_Alps-1U; ALPS-1U
SW-UP1: MX_Alps-1U; ALPS-1U
SW-V1: MX_Alps-1U; ALPS-1U
SW-W1: MX_Alps-1U; ALPS-1U
SW-X1: MX_Alps-1U; ALPS-1U
SW-Y1: MX_Alps-1U; ALPS-1U
SW-Z1: MX_Alps-1U; ALPS-1U
SW-[1: MX_Alps-1U; ALPS-1U
SW-\1, SW-\3: MX_Alps-1U; ALPS-1U
SW-\2: MX_Alps-1.5U; ALPS-1.5U
SW-]1: MX_Alps-1U; ALPS-1U
SW-`1: MX_Alps-1U; ALPS-1U
Stab-2U1: Stab-2U; MX-2U-Stab-Only
Stab-7U1: Stab-7U; MX-7U-Stab-Only-Reversed
Stab-225U1, Stab-225U2, Stab-225U3: Stab-2.25U; MX-2.25U-Stab-Only
Stab-275U1: Stab-2.75U; MX-2.75U-Stab-Only
Stab-625U1: Stab-6.25U; MX-6.25U-Stab-Only-Reversed

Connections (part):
COL0: SW-M1.1 (COL), SW-M3.1 (COL), SW-M5.1 (COL), SW-M7.1 (COL), SW-M9.1 (COL); also elsewhere on the board
COL1: SW-M2.1 (COL), SW-M4.1 (COL), SW-M6.1 (COL), SW-M8.1 (COL), SW-M10.1 (COL); also elsewhere on the board
COL2: SW-3800CAPS1.1 (COL), SW-CAPS1.1 (COL), SW-ESC1.1 (COL), SW-LCTRL1.1 (COL), SW-LCTRL2.1 (COL), SW-LSHIFT1.1 (COL), SW-LSHIFT2.1 (COL), SW-STEPCAPS1.1 (COL), SW-TAB1.1 (COL); also elsewhere on the board
COL3: SW-1.1 (COL), SW-A1.1 (COL), SW-LALT2.1 (COL), SW-LWIN1.1 (COL), SW-LWIN2.1 (COL), SW-LWIN3.1 (COL), SW-Q1.1 (COL), SW-\3.1 (COL); also elsewhere on the board
COL4: SW-2.1 (COL), SW-LALT1.1 (COL), SW-LALT3.1 (COL), SW-LALT4.1 (COL), SW-S1.1 (COL), SW-W1.1 (COL), SW-Z1.1 (COL); also elsewhere on the board
COL5: SW-3.1 (COL), SW-D1.1 (COL), SW-E1.1 (COL), SW-X1.1 (COL); also elsewhere on the board
COL6: SW-4.1 (COL), SW-C1.1 (COL), SW-F1.1 (COL), SW-R1.1 (COL), SW-SPACE225.1 (COL); also elsewhere on the board
COL7: SW-5.1 (COL), SW-G1.1 (COL), SW-T1.1 (COL), SW-V1.1 (COL); also elsewhere on the board
COL8: SW-6.1 (COL), SW-B1.1 (COL), SW-H1.1 (COL), SW-SPACE6.1 (COL), SW-SPACE7.1 (COL), SW-SPACE275.1 (COL), SW-SPACE625.1 (COL), SW-Y1.1 (COL); also elsewhere on the board
COL9: SW-7.1 (COL), SW-J1.1 (COL), SW-N1.1 (COL), SW-U1.1 (COL); also elsewhere on the board
COL10: SW-8.1 (COL), SW-I1.1 (COL), SW-K1.1 (COL), SW-M11.1 (COL); also elsewhere on the board
COL11: SW-9.1 (COL), SW-,1.1 (COL), SW-L1.1 (COL), SW-O1.1 (COL), SW-RALT2.1 (COL), SW-RALT3.1 (COL); also elsewhere on the board
COL12: SW-0.1 (COL), SW-.1.1 (COL), SW-;1.1 (COL), SW-MENU1.1 (COL), SW-MENU2.1 (COL), SW-P1.1 (COL), SW-RALT1.1 (COL); also elsewhere on the board
COL13: SW-'1.1 (COL), SW--1.1 (COL), SW-/1.1 (COL), SW-RCTRL1.1 (COL), SW-RCTRL2.1 (COL), SW-[1.1 (COL); also elsewhere on the board
COL14: SW-#1.1 (COL), SW-=1.1 (COL), SW-RSHFT1.1 (COL), SW-]1.1 (COL); also elsewhere on the board
COL15: SW-ANSIEN1.1 (COL), SW-BKSP1.1 (COL), SW-ISOEN1.1 (COL), SW-ISOEN2.1 (COL), SW-ISOEN3.1 (COL), SW-LEFT1.1 (COL), SW-\1.1 (COL), SW-\2.1 (COL); also elsewhere on the board
COL16: SW-DOWN1.1 (COL), SW-UP1.1 (COL), SW-`1.1 (COL); also elsewhere on the board
COL17: SW-DEL1.1 (COL), SW-END1.1 (COL), SW-PGDN1.1 (COL), SW-PGUP1.1 (COL), SW-RIGHT1.1 (COL); also elsewhere on the board
unnamed: D1.2 (A), SW-M1.2 (ROW)
unnamed: D2.2 (A), SW-M2.2 (ROW)
unnamed: D3.2 (A), SW-ESC1.2 (ROW)
unnamed: D4.2 (A), SW-1.2 (ROW)
unnamed: D5.2 (A), SW-2.2 (ROW)
unnamed: D6.2 (A), SW-3.2 (ROW)
unnamed: D7.2 (A), SW-4.2 (ROW)
unnamed: D8.2 (A), SW-5.2 (ROW)
unnamed: D9.2 (A), SW-6.2 (ROW)
unnamed: D10.2 (A), SW-7.2 (ROW)
unnamed: D11.2 (A), SW-8.2 (ROW)
unnamed: D12.2 (A), SW-9.2 (ROW)
unnamed: D13.2 (A), SW-0.2 (ROW)
unnamed: D14.2 (A), SW--1.2 (ROW)
unnamed: D15.2 (A), SW-=1.2 (ROW)
unnamed: D16.2 (A), SW-BKSP1.2 (ROW), SW-\1.2 (ROW)
unnamed: D17.2 (A), SW-`1.2 (ROW)
unnamed: D18.2 (A), SW-DEL1.2 (ROW)
unnamed: D19.2 (A), SW-M3.2 (ROW)
unnamed: D20.2 (A), SW-M4.2 (ROW)
unnamed: D21.2 (A), SW-TAB1.2 (ROW)
unnamed: D22.2 (A), SW-Q1.2 (ROW)
unnamed: D23.2 (A), SW-W1.2 (ROW)
unnamed: D24.2 (A), SW-E1.2 (ROW)
unnamed: D25.2 (A), SW-R1.2 (ROW)
unnamed: D26.2 (A), SW-T1.2 (ROW)
unnamed: D27.2 (A), SW-Y1.2 (ROW)
unnamed: D28.2 (A), SW-U1.2 (ROW)
unnamed: D29.2 (A), SW-I1.2 (ROW)
unnamed: D30.2 (A), SW-O1.2 (ROW)
unnamed: D31.2 (A), SW-P1.2 (ROW)
unnamed: D32.2 (A), SW-[1.2 (ROW)
unnamed: D33.2 (A), SW-]1.2 (ROW)
unnamed: D34.2 (A), SW-\2.2 (ROW)
unnamed: D35.2 (A), SW-PGUP1.2 (ROW)
unnamed: D36.2 (A), SW-M5.2 (ROW)
unnamed: D37.2 (A), SW-M6.2 (ROW)
unnamed: D38.2 (A), SW-3800CAPS1.2 (ROW), SW-CAPS1.2 (ROW), SW-STEPCAPS1.2 (ROW)
unnamed: D39.2 (A), SW-A1.2 (ROW)
unnamed: D40.2 (A), SW-S1.2 (ROW)
unnamed: D41.2 (A), SW-D1.2 (ROW)
unnamed: D42.2 (A), SW-F1.2 (ROW)
unnamed: D43.2 (A), SW-G1.2 (ROW)
unnamed: D44.2 (A), SW-H1.2 (ROW)
unnamed: D45.2 (A), SW-J1.2 (ROW)
unnamed: D46.2 (A), SW-K1.2 (ROW)
unnamed: D47.2 (A), SW-L1.2 (ROW)
unnamed: D48.2 (A), SW-;1.2 (ROW)
unnamed: D49.2 (A), SW-'1.2 (ROW)
unnamed: D50.2 (A), SW-#1.2 (ROW)
unnamed: D51.2 (A), SW-ANSIEN1.2 (ROW), SW-ISOEN1.2 (ROW), SW-ISOEN2.2 (ROW), SW-ISOEN3.2 (ROW)
unnamed: D52.2 (A), SW-PGDN1.2 (ROW)
unnamed: D53.2 (A), SW-M7.2 (ROW)
unnamed: D54.2 (A), SW-M8.2 (ROW)
unnamed: D55.2 (A), SW-LSHIFT1.2 (ROW), SW-LSHIFT2.2 (ROW)
unnamed: D56.2 (A), SW-\3.2 (ROW)
unnamed: D57.2 (A), SW-Z1.2 (ROW)
unnamed: D58.2 (A), SW-X1.2 (ROW)
unnamed: D59.2 (A), SW-C1.2 (ROW)
unnamed: D60.2 (A), SW-V1.2 (ROW)
unnamed: D61.2 (A), SW-B1.2 (ROW)
unnamed: D62.2 (A), SW-N1.2 (ROW)
unnamed: D63.2 (A), SW-M11.2 (ROW)
unnamed: D64.2 (A), SW-,1.2 (ROW)
unnamed: D65.2 (A), SW-.1.2 (ROW)
unnamed: D66.2 (A), SW-/1.2 (ROW)
unnamed: D67.2 (A), SW-RSHFT1.2 (ROW)
unnamed: D68.2 (A), SW-UP1.2 (ROW)
unnamed: D69.2 (A), SW-END1.2 (ROW)
unnamed: D70.2 (A), SW-M9.2 (ROW)
unnamed: D71.2 (A), SW-M10.2 (ROW)
unnamed: D72.2 (A), SW-LCTRL1.2 (ROW), SW-LCTRL2.2 (ROW)
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

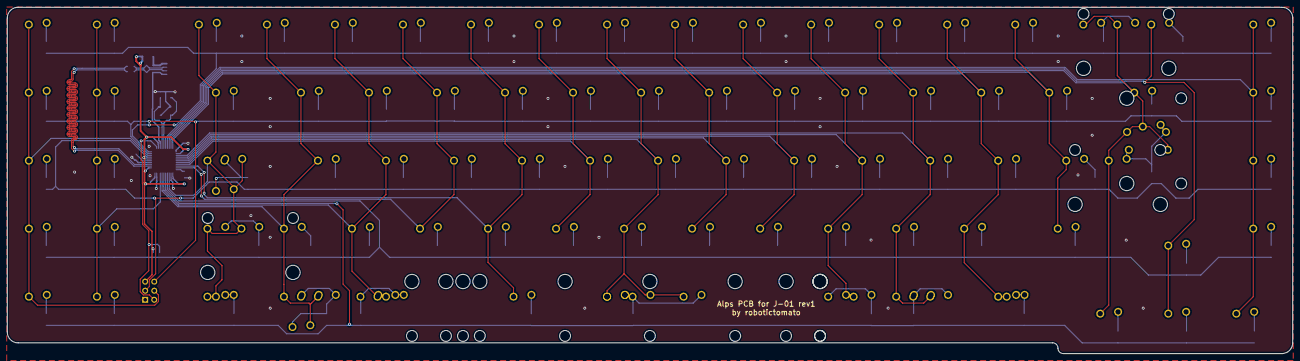
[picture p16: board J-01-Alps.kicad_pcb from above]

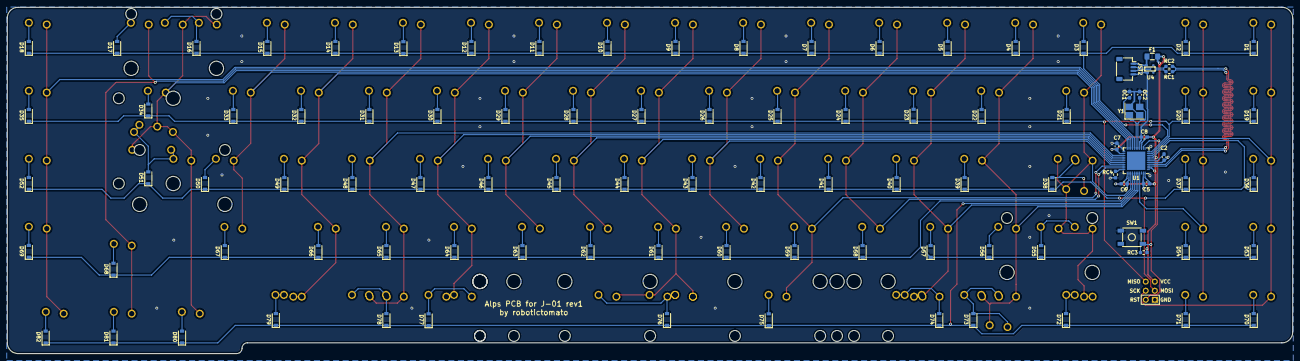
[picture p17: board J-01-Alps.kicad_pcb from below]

Board: 2 copper layers, 360.0 x 97.0 mm, 209 parts (100 on the bottom side), 117 nets.

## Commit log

2021-12-17 Adding submodules for libraries
    [J-01-Alps.kicad_pcb, J-01-Alps.sch]
2021-12-17 KiCad initialization
    Adding the library files to the KiCad project.
2021-12-17 Add JST library and start schematic
    [J-01-Alps.sch]
2021-12-17 Another attempt at adding more libraries
    [J-01-Alps.sch]
2021-12-19 MCU and Matrix Layout
    Continued work on the MCU component layout and the switch matrix.
    [J-01-Alps.sch, matrix.sch]
2021-12-19 Matrix work
    Additional work on the switch matrix.
    [matrix.sch]
2021-12-19 Matrix Draft complete
    First draft of the switch matrix is complete.
    [J-01-Alps.sch, matrix.sch]
2021-12-20 PCB layout started
    The beginning of the PCB layout - switch positions and two rows of diodes.
    [J-01-Alps.kicad_pcb, matrix.sch]
2021-12-22 Footprint changes
    Changed all of the MX+Alps footprints to Alps only. Also added MX Stabilizer footprints.
    [J-01-Alps.kicad_pcb, J-01-Alps.sch, matrix.sch]
2021-12-23 Initial routing and additional switch footprints
    More bottom row option support (6U, split spacebar), and the start of some column and row routing.
    [J-01-Alps.kicad_pcb, matrix.sch]
2021-12-25 Routing work continued
    Most routes placed. Will need to be optimized and cleaned up, but most paths have been figured out.
    [J-01-Alps.kicad_pcb]
2021-12-31 Continued work on layout
    Layout refinements, USB traces, etc.
    [J-01-Alps.kicad_pcb, J-01-Alps.sch]
2022-01-08 Verification of routing and dimension
    Finished verifying the routing is correct, and the edge-cut dimensions are correct. Double checked the separation between switch areas for Macro columns and arrows / 65% extension keys. Added renders.
    [J-01-Alps.kicad_pcb]
2022-01-08 Generate Gerber, BOM, and POS files
    Generated production files, including Gerbers, BOM for JLCPCB, and positioning files (specific to JLCPCB).
    [J-01-Alps-B_Cu.gbl, J-01-Alps-B_Mask.gbs, J-01-Alps-B_SilkS.gbo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]
2022-01-08 Add ZIP of BOM
    Added a Zip file to properly include the BOM and Positioning files.
2022-01-08 Modifications for QFN footprint
    Modifications for ATmega32U4-MU. Rerouting of USB traces, 5V lines, and other supporting components.
    [J-01-Alps.kicad_pcb, J-01-Alps.sch]
2022-01-09 Updated Gerber files
    Updated all production files for use at JLCPCB for manu.
    [J-01-Alps-B_Cu.gbl, J-01-Alps-B_Mask.gbs, J-01-Alps-B_SilkS.gbo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]
2022-02-27 Cleanup
    A few small cleanup updates.
    [J-01-Alps.sch]
2022-02-27 Additional cleanup
    Move to Kicad 6 changes - archive old versions of files.
    [J-01-Alps.kicad_pcb, J-01-Alps.kicad_sch, J-01-Alps.sch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]
2022-02-27 Kicad 6 DRC cleanup
    Changes to the DRC tool for Kicad 6 required additional cleanup.
    [J-01-Alps.kicad_pcb]
2022-02-28 Outline adjustment, footprint cleanup
    [J-01-Alps.kicad_pcb, matrix.kicad_sch]
2022-03-02 PCB dimension verification
    Double check of switch positions and edge dimensions.
    [J-01-Alps.kicad_pcb]
2022-03-05 Trace cleanup and ISO Enter
    Continued trace cleanup for multi-position keys. Added support for three ISO enter orientations - 1.25 vertical and horizontal, and 1.5u vertical.
    [J-01-Alps.kicad_pcb, J-01-Alps.kicad_sch, matrix.kicad_sch]
2022-03-06 Footprint cleanup, add AVR-ISP header footprint
    Some cleanup of the bottom row, ISO enter layout, and capslock footprints for more clearance. Addition of the AVR ISP header footprint and mapping to the MCU.
    [J-01-Alps.kicad_pcb, J-01-Alps.kicad_sch, matrix.kicad_sch]
2022-03-06 Updated Gerber, BOM, and positioning files
    Final checkout of Gerbers, BOM, and positioning files.
    [J-01-Alps-B_Cu.gbl, J-01-Alps-B_Mask.gbs, J-01-Alps-B_SilkS.gbo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]
2022-03-11 Created Zip file with BOM and Positioning files
2022-06-27 Content update - Gerber and plate files
    Added plate files directory and contents, removed excess Gerber files.
    [J-01-Alps-B_Cu.gbl, J-01-Alps-B_Mask.gbs, J-01-Alps-B_Silkscreen.gbo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]
2022-12-24 Silkscreen and edge cut changes, update to .step files
    Modified the edge cut profile to be compatible with the upcoming rev2 release of the J-01. Changed silkscreen on front of PCB through-holes to prevent solder from flowing through. Updated Gerbers. Changed 3D models to .step files for export.
    [J-01-Alps.kicad_pcb, SM04B-SRSS-TB(LF)(SN)--3DModel-STEP-56544.STEP]
2022-12-26 Small change to footprint clearance
    There was a mistake in one of the footprint clearances. Fixed.
    [J-01-Alps.kicad_pcb]
